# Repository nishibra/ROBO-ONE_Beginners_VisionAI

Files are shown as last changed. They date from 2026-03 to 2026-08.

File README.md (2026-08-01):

# ROBO-ONE_Beginners_VisionAI型ロボット

操縦型と自律制御型と同じ外形でカメラを搭載したロボットです。CPUにはRaspi5を使用し、深層機械学習や深層強化学習に加えてフィジカルAIなどを戦いを通して学べる教材として提供するものです。

---
### [機械設計](Mechanical_Design.md)
### [電子回路](Electronic_Circuit.md)
- 2026/8/1 "製作費を抑えた低コストバージョン"の説明を追加しました。
### [ソフトウェア](Software.md)
### [シミュレーション](Simulation.md)
---
### ROBO-ONE Beginners movies [動画](https://www.youtube.com/channel/UCuxCMnABbm_D5GusLxcCyIQ)
### ROBO-ONE Beginners 競技規則　[競技規則](https://github.com/nishibra/ROBO-ONE_Beginners)
---

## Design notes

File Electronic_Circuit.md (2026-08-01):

### ROBO-ONE_Beginners_VisionAI
# Electronic_Circuit

## 概要
Raspi5とカメラを使用し画像処理や深層強化学習などフィジカルAIの学習が電子回路に詳しくなくても可能なものとします。
- cpu: Raspi5 RAM 4Gbyte以上　SDカード 64Gbyte以上
- Raspi Camera csi接続
- Hat:5v電源 serial servo control/ i2c/ fan control/ RTC
- IMU BNO055など i2c接続
- ADC ADS1115など i2c接続

### 全体図
まずはカメラとIMUでどこまでいけるかトライして頂けることを期待します。TofセンサーとPSDセンサーは搭載していません。PSDセンサーは必要なら搭載できるようBKTは準備しました。ハットを使用しできるだけはんだ付けを少なくしました。

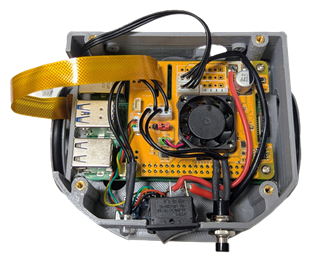
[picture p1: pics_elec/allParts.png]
RaspiAll


### Raspi5
ここではRaspi5を使用します。Raspi4でもほとんどのサンプルは動作しますが遅くです。スタートとして使用するには可能です。メモリーは4G以上あれば良いでしょう。

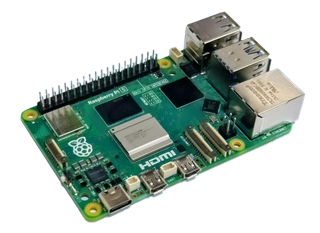
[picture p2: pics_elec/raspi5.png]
Raspi5


[Raspi5購入先](https://www.amazon.co.jp/dp/B0CPDJ8FNK?ref=ppx_yo2ov_dt_b_fed_asin_title)

### Hat
はんだ付けの極力避けるため以下のHatを使用します。Serial servo controlや電源、Fanが搭載されており、コンパクトで搭載性が非常に良いものです。

#### (BTE100B)(仕様変更中)
hat

[HAT購入先](https://www.besttechnology.co.jp/modules/knowledge/?BTE100B%20DXHAT)

#### HeatSink
画像処理を行うには電力消費が増大するためヒートシンクとFanの搭載が不可欠です。
以下のヒートシンクをRaspi5の赤丸部に貼り付けた後にハットを取り付けてください。

sink
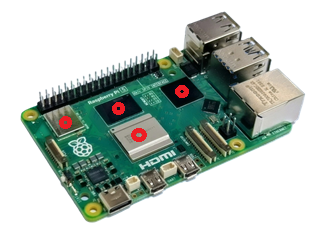
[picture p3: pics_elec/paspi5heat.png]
Pi5Heat


[Heatsink購入先](https://www.amazon.co.jp/dp/B0F8V6TK9M?ref=ppx_yo2ov_dt_b_fed_asin_title&th=1)

#### 電源廻り
電源スイッチはHatの電源入力とバッテリー接続コネクターの間に接続し写真のように取り付けます。ただしOSを週利用したのち電源スイッチを切るようにしてください。
右側のまどからRaspi5のスイッチが見えます。PCと接続していない場合はこのスイッチを長押ししてください。同じ窓から見えるLEDが赤くなってから電源を落として下さい。

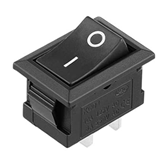
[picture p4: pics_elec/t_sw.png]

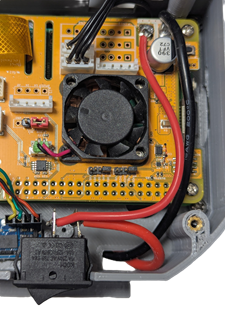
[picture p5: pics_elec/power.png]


このスイッチは以下より入手できます。

[sw購入先](https://www.amazon.co.jp/dp/B09QJQ55F8?ref=ppx_yo2ov_dt_b_fed_asin_title&th=1)

### CSI camera
Raspiカメラは以下を使用します。
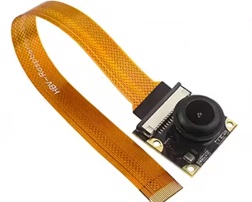
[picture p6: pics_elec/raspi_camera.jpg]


ハットを搭載する前にcam/disp 0にフラットケーブルを挿入しておきます。

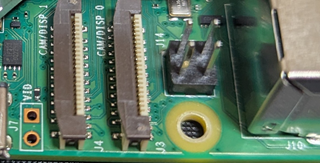
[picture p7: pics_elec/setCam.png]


#### camera: csi
Raspiカメラには以下のものがあります。レンズはFOV違いでいろいろありますが、130°程度が画像のひずみ変形も少なく使いやすいでしょう。

[Raspberry Pi 5 カメラ 5MP 1080P 130°](https://ja.aliexpress.com/item/1005006790000090.html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)

[1080Pミニカメラモジュール160°広角 購入先](https://www.amazon.co.jp/dp/B0D2BMH1BB?ref=ppx_yo2ov_dt_b_fed_asin_title)

#### Flexible cable
フラットケーブルは10～15cmの長さのものを使用します。

[CSIケーブル 15-22pin FPC フレキシブル 100mm購入先](https://www.amazon.co.jp/dp/B0DNFP5QJR?ref=ppx_yo2ov_dt_b_fed_asin_title&th=1)

### 入出力
#### IMU bno055
I2CにQWICコネクターで接続します。ROBO-ONE Beginners autoと同様に接続してください。

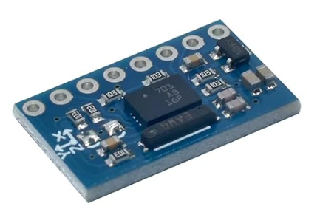
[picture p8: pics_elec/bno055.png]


[Qwic I2C コネクター購入先](https://www.amazon.co.jp/elechawk-%E3%82%B1%E3%83%BC%E3%83%96%E3%83%AB%E3%82%AD%E3%83%83%E3%83%88-SparkFun-%E3%82%BB%E3%83%B3%E3%82%B5%E3%83%BC%E3%83%9C%E3%83%BC%E3%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)

CPU caseには下の写真のように配置します。ロボットの前後がX軸、左右がY軸、基板面に垂直な方向がZ軸です。

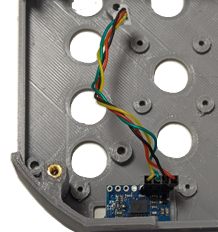
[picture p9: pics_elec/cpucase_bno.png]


#### push sw　および LED
push sw　および LEDはROBO-ONE Beginners autoと同じものが使用できます。以下のものも使えamazonでも入手できます。

sw

[push_sw購入先](https://www.amazon.co.jp/dp/B0D4PX1V4Q?ref=ppx_yo2ov_dt_b_fed_asin_title)

回路図は以下の通りで、スイッチのプルアップ抵抗はRaspi5の内部でブルアップすれば取り付ける必要はありません。

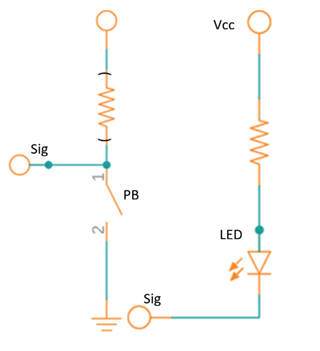
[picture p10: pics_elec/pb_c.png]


以下のようにはんだ付けし熱収縮チューブで被覆します。

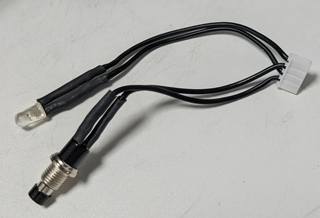
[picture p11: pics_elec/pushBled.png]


#### ADC
Raspi5ではI2Cを通してADCを接続し、PSDからのアナログ値を距離に変換して使用します。

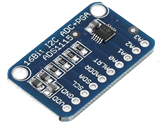
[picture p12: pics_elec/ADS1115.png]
ADC


[ADC購入先](https://www.amazon.co.jp/Walfront-1%E5%80%8BADS1115-16%E3%83%93%E3%83%83%E3%83%88I2C-ADC%E9%96%8B%E7%99%BA%E3%83%9C%E3%83%BC%E3%83%89%E3%82%A2%E3%83%8A%E3%83%AD%E3%8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)

### battery
Zeeeのバッテリーは比較的安定して使用できます。10個1年使用して今のところ問題ありません。
1350mAhのバッテリーを使用できます。2200mAhのバッテリーも搭載可能です。

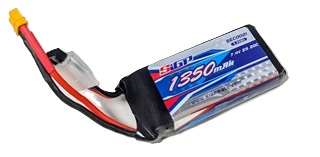
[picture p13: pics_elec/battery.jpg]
Battery


## servo:KRS3301/KRS3304-R2
KRS-3300シリーズのすべてのサーボモーターを使用できると同時にバッテリー(Lipoバッテリー2セル/7.4Vなど)は自由に自己責任で使用できます。
サーボモータについては通常KRS-3301を使用します。倒立伸子を行う場合はKRS3304-R2を使うと良いでしょう。
サーボの設定はROBO-ONE Beginners autoと同じとしますがトルク特性は以下のように少し変更した方がシミュレーションと会わせやすいでしょう。

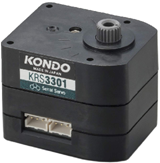
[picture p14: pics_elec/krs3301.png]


[サーボ購入先](https://kondo-robot.com/product/krs-3304r2-ics)

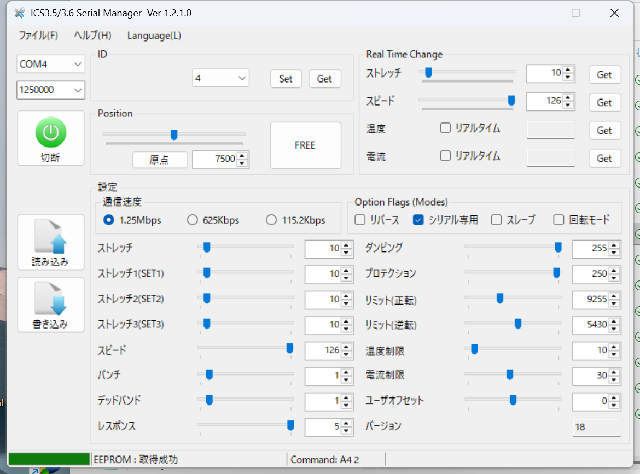
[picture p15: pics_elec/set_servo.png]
servo


---
#### BTE100Bのconfig.txtに追記する情報

プッシュスイッチを押下するとログアウト
```
[all]
dtoverlay=gpio-shutdown,gpio_pin=17
dtoverlay=gpio-poweroff,gpiopin=4,active_low=1
```
LinuxをGUIで起動している場合は、プッシュスイッチを押下するとログアウトのプロンプトが表示され、タイムアウトするかダイアログのpower offを選択するまでシャットダウンが行われません。プッシュスイッチ操作によってシンプルにシャットダウン処理を行わせるには、GNOMEの設定を変更する必要があります。なおログインしていない状態ではこの設定は効果がありません。

```
gsettings set org.gnome.SessionManager logout-prompt false
```
冷却ファンのON-OFF
```
[all]
dtoverlay=gpio-fan,gpiopin=19,temp=50000
temp=50000は50℃で冷却ファンをONする意味で、摂氏度の1000倍の値を指定
設定温度を10℃下回るとファンはOFFする
```
RTC
```
[pi5]
dtparam=rtc=off
[all]
dtparam=i2c_arm=on
dtoverlay=i2c-rtc,ds3231
```
UART
```
[pi3]
init_uart_clock=64000000
dtoverlay=uart0=on
dtoverlay=pi3-miniuart-bt
 
[pi4]
init_uart_clock=64000000
#UART1を活性化
dtoverlay=uart1,txd1_pin=14,rxd1_pin=15
#UART2を活性化
dtoverlay=uart2,txd2_pin=0,rxd2_pin=1
#UART4を活性化
dtoverlay=uart4,txd4_pin=8,rxd4_pin=9
使用するポートのみを活性化する事を推奨。Linux上でのデバイス名は概ねttyAMAのプレフィクスで始まる。
またRaspberry Pi 3/Zeroの場合はcmdline.txtに記述されている「console=serial0,115200」を削除する事
```

---
## 製作費を抑えた低コストバージョン
最近は半導体の価格が上がっているため、できるだけコストを抑えて製作できる方法を検討しました。
また、これまでのモデル（auto）からの移行もスムーズに行えるよう、共通で使える部品を可能な限り採用しています。

### メモリ（RAM）の見直しによるコスト削減
Raspberry Pi 5 は搭載されているメモリ容量によって価格が大きく変わります。
今回のように **RAM 2GB や 1GB のモデルを選ぶことで、本体費用をぐっと安く抑えることが可能**です。
もし運用中にメモリが足りなくなった場合でも、**画像処理の解像度を少し落とすなどの工夫で十分対応できる**見込みです。

### 部品の購入先リンク
製作に必要な部品の購入先一覧です。

* **Raspberry Pi 5 (2GB RAM)**
[購入先](https://www.amazon.co.jp/Raspberry-Pi-SC1110-5-2GB-RAM%E3%80%82/dp/B0DDL91V2R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)
* **Raspberry Pi 5 (1GB RAM)**
[購入先](https://www.amazon.co.jp/Raspberry-Pi-1GB-RAM-%E3%80%82/dp/B0G668D1R8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)
* **高効率 8A DC-DC 降圧コンバータボード（25V → 3.3V/5V/9V/12V）**
[購入先](https://ja.aliexpress.com/item/1005009516551580.html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)

### 構成と写真のご案内
写真と合わせて配線や接続のイメージをご確認ください。

* **構成全体写真**
ファン付きの Raspberry Pi 5 に、5V電源・IMU（慣性計測装置）・シリアル変換ボード・サーボ分配器を取り付けた状態です。IMU（慣性計測装置）・シリアル変換ボード・サーボ分配器はautoのものを使用します。

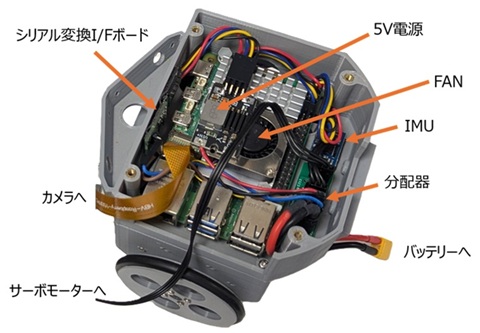
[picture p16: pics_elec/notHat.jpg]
全体図


* **実態配線図**
Raspberry Pi 5 に5V電源、シリアル変換ボード、サーボ分配器を接続した配線図です。

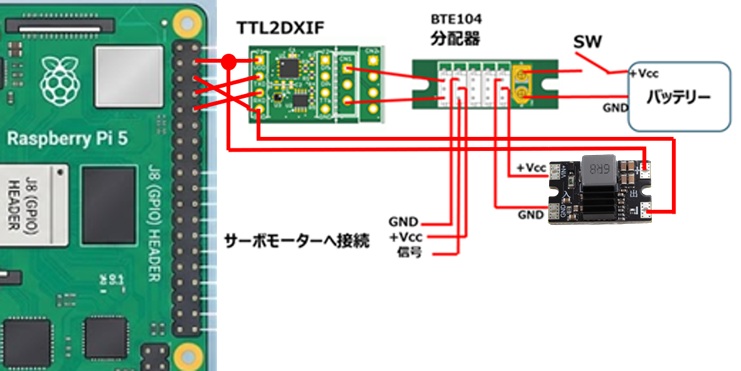
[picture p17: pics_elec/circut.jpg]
配線図


* **IMU接続写真**
Raspberry Pi 5 に IMU を I2C 接続した様子です。

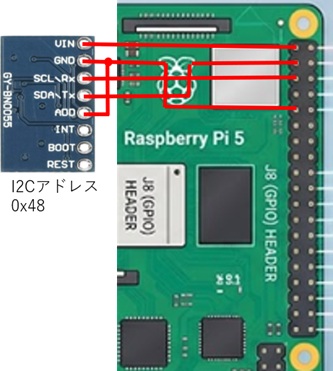
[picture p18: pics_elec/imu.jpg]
IMU接続図


### 組み立てのコツと注意点

* **組み立てやすさ**
はんだ付けを行う箇所は数か所だけですので、電子工作が初めての方や初心者の方でも比較的簡単に作ることができます。
* **パーツの固定方法**

   **サーボ分配器：** 固定用のボスが付いているため、ビス（ネジ）でしっかり固定できます。

   **その他のボード：** ショートを防ぐため、絶縁に気を付けながら両面テープ等で固定してください。

* **プログラムの互換性**
I2Cアドレスおよびシリアルポートの設定は HAT（拡張基板）を使用した時と同じになっています。そのため、**既存のプログラムをそのまま変更せずに動かすことが可能**です。

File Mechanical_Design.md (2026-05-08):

### ROBO-ONE_Beginners_VisionAI
# Mechanical_Design

## 1.コンセプト
このロボットはRaspberry Pi 5を使った画像処理やAIの学習向けのロボットです。
外形寸法はROBO-ONE Beginners auto型と同じですがCPUはRaspi picoからRaspi-5に替わり、カメラが搭載されます。足回りとアーム部は部品点数の低減と組み立て性の改善を図りました。Raspi5を使用し深層学習を実行することから電力消費増と発熱への対応とバッテリの容量アップ品の搭載が可能なものとしました。
#### 全体写真
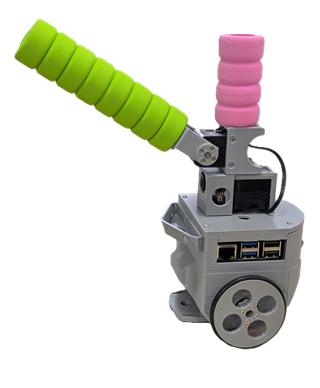
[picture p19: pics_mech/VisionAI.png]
VisionAI

#### 全体図
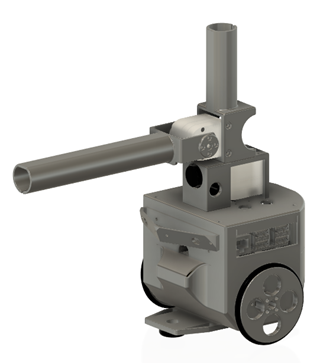
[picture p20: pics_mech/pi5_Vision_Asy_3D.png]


## 2.CPU case
外形寸法はROBO-ONE Beginners autoのpico CPU caseと同じサイズに収めました。後部のPSD用ブラケットはCPU caseと一体化、前方は分離型のままでTofセンサーは廃止しカメラを使った画像処理で対応することとします。
#### CPU case
CPU case cover締め付けボスにM2.5のインサートを挿入しておきます。挿入方法はROBO-ONE Beginners autoと同じですのでそちらをご参照ください。
CPUはM2.5-8mmのねじでケース下より締め付けます。

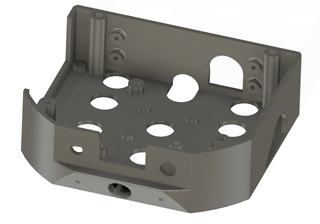
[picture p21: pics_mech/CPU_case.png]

VisionAI

下の写真のように事前にヒートシンクを取り付けたCPUボードとハットをマウント用ディスタンスにねじM2.5-4mmをハット上部にねじで締め付けておきます。この時カメラ用フラットケーブルを接続しておきます。詳細は電子回路編でご確認ください。

VisionAI

### PSD BKT
PSD BKTはCPU caseにM2-5mmのタッピングビスでねじ止めします。

VisionAI

### CPU case cover
CPU case coverはCPU caseに4本のM2.5-8mmねじで締め付けます。更にアームまわりを搭載します。

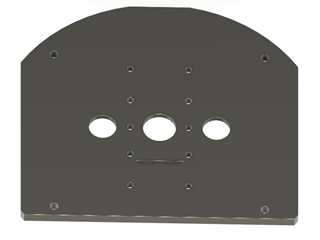
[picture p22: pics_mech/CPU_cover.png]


## 3.アーム廻り
アーム廻りは写真のように組み立てます。

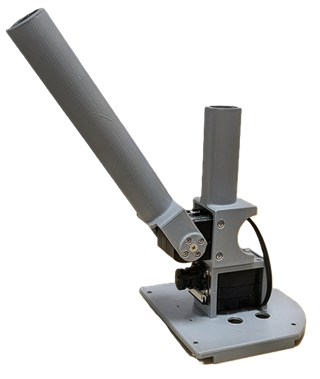
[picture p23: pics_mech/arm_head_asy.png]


#### Pan servo bkt
Pan servo bktにはPan用サーボモーターを4本のM2-5mmで締め付けます。CPU case coverとPan servo bktは4本のM2-10mmタッピングビスで締め付けます。

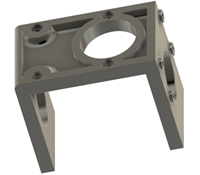
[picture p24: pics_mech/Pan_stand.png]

VisionAI

Pan_standを3dプリンターで製作する場合はBrimをつけ、横方向からプリントするようにします。

#### Tilt_bkt and Head
Tiltサーボモーターの固定とヘッドを一体化しました。サーボホーンとの締め付けはM2-8mmのねじで、サーボとの締め付けはM3-8mm(近藤科学M3-8低頭ホーン止めビス)で締め付けます。渋りが無いことを確認します。渋りがある場合はペーパーやすりなどで渋り面を仕上げます。

VisionAI

#### Arm
アームとBKTを一体化しました。サーボホーンは両軸とし、いずれもM2-5mmのねじで締め付けます。

VisionAI

### Head と Armの保護

Head部とArm部には安全や器物保護のためスポンジのドアノブカバーを使用します。
ピンクと紫は半分に切ってHead部に使用します。赤コーナーの場合はピンク、青コーナーは紫です。Headおよびアームはそれぞれスポンジを交換しやすくするためにスリットを入れています。

donb  

[購入先](https://amzn.asia/d/89CXsD9) 

購入にあたっては似たようないくつかの製品があり、内径寸法が多少異なる場合がありますので注意してください。

### カメラの取り付け
カメラの取り付けは4本のM2-5mmのタッピングビスで締め付けます。CPUカバーのスリット部からカメラ用フラットケーブルを引き出し接続します。裏表がありますので間違えないようにしてください。

VisionAI

#### camera cover
Camera coverはパチッというまで押し込むと固定されます。

VisionAI

### 4.足回り

ロボットのセンサー、電子回路、ソフトウェアは自由に変更できるものとします。またKRS-3300シリーズのすべてのサーボモーターを使用できると同時にバッテリー(Lipoバッテリー2セル/7.4Vなど)は自由に自己責任で使用できます。

### Wheel
wheelは1partsとしました。O-ringを入れることで完成です。

VisionAI
VisionAI

O-ringは以下より購入可能です。

[5個入り Oリング ニトリルゴム 50mm x 60mm x 5mm ブラック](https://www.amazon.co.jp/dp/B07W3BR9TY?ref=ppx_yo2ov_dt_b_fed_asin_title&th=1)

サーボモータにはサーボホーンに直接取り付けることができます。ねじはM2-12mmを使用してください。

VisionAI 
  
### シャーシ
キャスタ部にはスライダーを採用しました。滑りやすくなり走行抵抗や走行音が少なくなりました。スライダーはシャーシの取り付け部丸い部分のセンターに取り付けてます。このピッチが90mm,70mm,50mmとあり、昇段昇級の審査に使われます。ボディとの取り付けはM2-10mmのタッピングビスで取り付けます。

VisionAI
VisionAI

[スライダー購入先](https://www.amazon.co.jp/dp/B0DFGZZ4GH?ref=ppx_yo2ov_dt_b_fed_asin_title)

### body
モノコックとし、サーボモータを90度毎に自由にセットできるようにしました。これにより容量の大きなバッテリーの搭載が可能となります。
リチウムポリマーの7.4V2000mAH程度のバッテリーの搭載が工夫次第で可能です。
CPUケースの取り付けボス部にはインサートを埋め込みます。
M2.5のインサートを使用しています。

VisionAI
VisionAI

上の写真のようにサーボモーターを配置するとしたの写真のようにバッテリーが搭載でき、重量バランスがとりやくなります。またCPU caseをくみ上げる前にサーボモーターの設定は行っておきます。ボーレイト125000、IDは右側を1、左側を2と設定するとサンプルプログラムがそのまま使えます。

VisionAI

### Battery cover
バッテリの交換性向上のため、Battery coverのねじ止めはやめ、パッチンと挿入できるようにしました。バッテリーを交換したらカバーの片側を挿入し反対側を押し込んでください。外すときは上部の半円の部分に爪で出ているのでこれを引っ張り外してください。3Dプリンターで製作する場合はBrimを付けてください。

VisionAI
VisionAI

### stlデータ
3dprinterで使用できるstlファイルはstlフォルダーにありますのでご利用ください。セット面をサポートなしでプリントできるよう考えて見てください。すべてサポートなしでプリント可能です。

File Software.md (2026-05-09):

### ROBO-ONE_Beginners_VisionAI
# Software
## コンセプト
このロボットはRaspberry Pi 5を使用した初心者向けのVision AI型ロボットです。最新のAIライブラリを活用し、物体認識などの機械学習や、シミュレーションを用いた強化学習を学ぶことができます。

## ハード / OS / I/O 概要

* **CPU**: Raspberry Pi 5 (Memory 4GB以上推奨)
* **OS**: Raspberry Pi OS Trixie (Debian 13) 64-bit
* **言語**: Python 3.11以降
* **通信プロトコル**:
　* **Serial (UART)**: サーボモーター制御用 (KRSサーボ等)
　* **I2C**: IMU (慣性計測装置) / ADC (アナログ-デジタル変換) 用

## Install 手順
### 1. SDカードの作成
Raspberry Pi Imagerを使用し、Device:Raspi5 OS:Trixieを選択します。

gameController

* **OS**: Raspberry Pi OS (64-bit) Trixie
* **設定**: 書き込み時に「OSカスタマイズ」でホスト名、Wi-Fi、SSHを有効にしておくと、その後の作業がスムーズです。

### 2. OSとConfigの設定

Raspberry Pi 5を起動し、ターミナルで以下の設定を行います。

#### インターフェースの有効化

`sudo raspi-config` を実行し、以下の項目を **Enable** にします。

* Interface Options -> **I2C**
* Interface Options -> **Serial Port** (Login shell: No / Hardware: Yes)
* Interface Options -> **VNC** (必要に応じて)

#### Raspberry Pi Connect のセットアップ

ブラウザ経由でリモートデスクトップ操作を可能にします。

```bash
sudo apt update
sudo apt install rpi-connect
# インストール後、画面右上のアイコンまたはコマンドでサインイン

```

#### 冷却ファンの設定

`sudo nano /boot/firmware/config.txt` を開き、末尾に追記します。

```text
[all]
dtoverlay=gpio-fan,gpiopin=19,temp=50000

```

> **Note**: `temp=50000` は50℃でファンが始動することを意味します。AI処理中は発熱が激しいため、この設定は必須です。

### 3. I/O関係の接続確認

接続されたデバイスが認識されているか確認します。

```bash
# I2Cデバイスの確認（アドレスが表示されればOK）
i2cdetect -y 1

# シリアルポートの確認
ls /dev/ttyAMA0

```

## 開発環境（venv）の構築

OS標準のPython環境を汚さないよう、仮想環境（venv）を使用します。Trixieでは `pip install` を直接行うとエラーになるため、この手順は必須です。

### 仮想環境の作成と有効化

```bash
sudo apt update && sudo apt upgrade -y
mkdir ~/robot_project
cd ~/robot_project

# システムパッケージ（Picamera2など）を共有して作成
python3 -m venv venv --system-site-packages

# 有効化（作業開始時に毎回実行）
source venv/bin/activate
```
### 必要なライブラリのインストール
シミュレーション環境や画像処理のライブラリーをインストールします。mujocoやYoloがRaspi5でも使えます。

```bash
pip install --upgrade pip
pip install ultralytics  # YOLO (物体認識)
pip install mujoco gymnasium stable-baselines3  # 強化学習セット
pip install numpy

```
* Yolo26: `ultralytics` を入れることで、OpenCVも導入されるので、カメラ映像から即座にリアルタイム物体検知や処理が可能になります。
* 起動時自動実行: ロボットとして自律動作させる場合は、`systemd` を使って venv 内の python スクリプトを自動起動する設定を追加すると便利です。
* 電力不足注意: Raspberry Pi 5は 5V/5A の電源を推奨します。AI処理中にカメラやサーボを動かすと電圧降下（低電圧警告）が発生しやすいため、高品質な電源を使用してください。

---
## カメラ（rpicam-apps / Picamera2）の使い方
Raspberry Pi 5では従来の `raspistill` ではなく `rpicam-apps` を使用します。

### 基本コマンド
* プレビュー表示: `rpicam-hello -t 0`
* カメラ一覧確認: `rpicam-hello --list-cameras`
* 静止画保存: `rpicam-still -o test.jpg`

### Pythonでの画像処理
OpenCVとPicamera2を組み合わせる際、色の並び（色空間）に注意が必要です。
* 色の変換: Picamera2は RGB形式で画像を取得しますが、OpenCV（cv2）はBGR形式として処理します。
```python
# 変換例
import cv2
img_bgr = cv2.cvtColor(img_rgb, cv2.COLOR_RGB2BGR)
```
* フォーマット: メモリ効率を上げるため、`format='RGB888'` を指定してキャプチャすることを推奨します。

pi-cameraのsample programを以下に置きました。

example/etc/picamcam.py

---
## YOLO11の使用方法

YOLOはどんどん進化しており、簡単にインストールでき、使用できる便利な物体認識の深層学習手法です。また最近エッジおよび低電力デバイス向けに設計されたYOLO26も使えます。

[Yolo26](https://docs.ultralytics.com/ja/models/yolo26/)

以下はYolo11の物体認識のプログラムです。

example/etc/inf11_cam.py

---

## KRSのコントロール
krs-driver_rp5.pyはROBO-ONE Beginners autoのシリアルポートを変更したものです。使い方は同じです。

## IMU I2C取り込み
BNO055をi2cのボートと使用するライブラリーを変更すれば、使用方法はROBO-ONE Beginners autのものと同じです。

## ADC PSD取り込み
Raspi5にはADCが無いので、i2c接続のADCを使用します。
Raspberry Pi 5（ラズパイ5）で高性能な16bit ADC（アナログ-デジタルコンバータ）である**ADS1115**を使用する方法を解説します。
ラズパイ5では、これまでのモデルと異なりGPIOの制御方式が変更されていますが、Pythonのライブラリ（Adafruit CircuitPython）を使用すれば、従来通り簡単に扱うことができます。

### 1. 配線（接続方法）

ADS1115は**I2C**プロトコルを使用します。ラズパイ5のピン配置に合わせて以下のように接続してください。

| ADS1115 ピン | Raspberry Pi 5 ピン | 役割 |
| :--- | :--- | :--- |
| **VDD** | 3.3V (Pin 1) | 電源 (3.3V推奨) |
| **GND** | GND (Pin 9) | グラウンド |
| **SCL** | SCL (Pin 5) | I2C クロック |
| **SDA** | SDA (Pin 3) | I2C データ |
| **ADDR** | GNDへ接続 | I2Cアドレスを `0x48` に設定 |

### 2. ラズパイの設定

まず、I2Cインターフェースを有効にする必要があります。

1.  ターミナルで `sudo raspi-config` を実行。
2.  **Interface Options** -> **I2C** を選択し、**Yes** を選んで有効化します。
3.  再起動後、正しく認識されているか確認します。
    ```bash
    ls /dev/i2c*
    ```
    `/dev/i2c-1` が表示されればOKです。

### 3. ライブラリのインストール

ラズパイ5では、Python環境の競合を避けるために**仮想環境（venv）**の使用が推奨されています。

```bash
# 仮想環境の作成と有効化
python -m venv env
source env/bin/activate

# 必要なライブラリのインストール
pip install adafruit-circuitpython-ads1x15
```
### 4. Pythonコードの例
以下のコードは、`A0`ピンに入力された電圧を読み取り、コンソールに表示するシンプルな例です。

```python
import time
import board
import busio
import adafruit_ads1x15.ads1115 as ADS
from adafruit_ads1x15.analog_in import AnalogIn

# I2Cバスの初期化
i2c = busio.I2C(board.SCL, board.SDA)

# ADS1115オブジェクトの作成
ads = ADS.ADS1115(i2c)

# A0ピンをアナログ入力として設定
chan = AnalogIn(ads, ADS.P0)

print(f"{'電圧(V)':>10} {'数値':>10}")
print("-" * 25)

try:
    while True:
        # chan.value は 0-65535 の範囲 (16bit)
        # chan.voltage は 実際の電圧
        print(f"{chan.voltage:10.4f}V {chan.value:10}")
        time.sleep(0.5)
except KeyboardInterrupt:
    print("\n終了します")
```

知っておくと役立つポイント
* ゲイン（増幅率）の設定:
    デフォルトでは最大4.096Vまで測定可能です。これより小さい電圧を精密に測りたい場合は、`ads.gain = 2`（最大2.048V）のように設定変更できます。
* 差動入力:
    2つのピンの電圧差を測る場合は、`AnalogIn(ads, ADS.P0, ADS.P1)` のように指定します。
* サンプリングレート:
    `ads.data_rate = 860` と設定することで、秒間最大860回の高速サンプリングが可能です。
---

## Game controllerの接続
RaspiOSに接続します。Raspi ConnectからRaspiに接続します。Bluetoothを探して接続します。いろいろなコントローラーが接続できると思います。
ここでは8bitDo lite2に接続します。

gameController
gameController

[購入先](https://www.amazon.co.jp/8BitDo-Lite-Switch%E3%80%81Switch-Lite%E3%80%81Android%E3%80%81Raspberry-Pi%EF%BC%88%E3%82%BF%E3%83%BC%E3%82%B3%E3%82%A4%E3%82%BA%EF%BC%89%E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)

#### Game controllerのサンプルプログラム
以下のプログラムは4軸のサーボモータをコントロールするprogramです。ここまでで出来れば操縦型で参加できます。

example/etc/joy.py
```python
import pygame
import time
import serial
from krs_driver_rp5 import * 
#servo id
id_r=1
id_l=2
id_pan=3
id_tilt=4
#
ct=7500
ct_pan=6128
ct_tilt=7500
#
krs=KRSdriver()
#
def arm(pan,tilt):
    krs.set_position_ret(id_pan,ct_pan+pan)
    krs.set_position_ret(id_tilt,ct_tilt-tilt)
#
def drive(r_sp,l_sp):
    krs.set_position_ret(2,ct-l_sp)
    krs.set_position_ret(1,ct+r_sp)
#
def free_all():
    krs.read_position_set_free(1)
    krs.read_position_set_free(2)
    krs.read_position_set_free(3)
    krs.read_position_set_free(4)  
#
def main():
	# Pygameの初期化（コントローラー用）
    pygame.init()
    pygame.joystick.init()
    while pygame.joystick.get_count() == 0:
        pygame.event.pump() # イベントキューを更新
        time.sleep(0.1)     # CPU負荷を抑えるための待機
    joystick = pygame.joystick.Joystick(0)
    joystick.init()
    print(f"Using: {joystick.get_name()}")
    #
    try:
        while(True) :
            pygame.event.pump()
            bu=joystick.get_button(0) # A
            bu2=joystick.get_button(1)# B
            bu3=joystick.get_button(3)# Y
            bu4=joystick.get_button(4)# Y
            bu6=joystick.get_button(6)# L1
            bu8=joystick.get_button(8)# L1
            if bu!=0: 
                drive(0,0)
            elif bu2!=0:
                free_all()
            elif bu6!=0:
                arm(int(5000*joystick.get_axis(2)),2800)
            elif bu8!=0:
                arm(int(5000*joystick.get_axis(2)),-3800)                
            else:
                fr=int(-300*joystick.get_axis(1))
                rf=int(100*joystick.get_axis(0))
                arm(int(5000*joystick.get_axis(2)),int(-5000*joystick.get_axis(3)))
                drive(fr-rf,fr+rf)
            time.sleep(0.01)
    except KeyboardInterrupt:
        print("\n終了します")
        pygame.quit()
        free_all()
#
if __name__ == "__main__":
    main()
```

---

## systemd による自動起動の設定手順
大会では電源を入れれば自動起動で操縦可能にします。

### 1. サービスファイルの作成

以下のコマンドで、新しいサービス設定ファイルを作成します（ファイル名は `my_robot.service` とします）。

```bash
sudo nano /etc/systemd/system/my_robot.service

```

### 2. 設定内容の記述

以下の内容をコピー＆ペーストしてください。各パスはご自身の環境に合わせて書き換えてください。

```ini
[Unit]
Description=My Vision AI Robot Service
After=network.target

[Service]
# 実行ユーザー（通常は pi）
User=nishi
# プログラムがあるディレクトリ
WorkingDirectory=/home/nishi/begin
# 仮想環境内のpythonパスを直接指定して実行
ExecStart=/home/nishi/begin/venv/bin/python3 /home/nishi/begin/rf/main.py
# 異常終了した時に5秒後に再起動する設定
Restart=always
RestartSec=5
# 標準出力（ログ）の送り先
StandardOutput=inherit
StandardError=inherit

[Install]
WantedBy=multi-user.target

```

### 3. サービスの有効化と起動

ファイルを保存（`Ctrl+O` -> `Enter`）し、エディタを終了（`Ctrl+X`）したら、以下のコマンドでシステムに反映させます。

```bash
# 設定の再読み込み
sudo systemctl daemon-reload

# 自動起動の有効化
sudo systemctl enable my_robot.service
# 無効化
sudo systemctl disable my_robot.service
# 今すぐ起動（テスト）
sudo systemctl start my_robot.service

```
### 4. 運用で役立つコマンド

自動起動を設定した後は、画面に何も表示されないため「本当に動いているか？」を確認する術を知っておく必要があります。

* **状態の確認**:
`systemctl status my_robot.service`
（実行中か、エラーで止まっているかが一目でわかります）
* **ログのリアルタイム確認**:
`journalctl -u my_robot.service -f`
（Pythonの `print()` 内容をリアルタイムで監視できます。デバッグに最適です）
* **停止・再起動**:
`sudo systemctl stop my_robot.service` / `sudo systemctl restart my_robot.service`---

---

## 【補足】Raspberry Pi Connect の導入・利用手順

Raspberry Pi Connectを使うと、ブラウザ越しにどこからでもRaspberry Piのデスクトップにアクセスできます。セットアップを以下のステップに分けて解説します。

### 1. 準備：OSのインストール

Raspberry Pi Connectを利用するには、OSのバージョンと種類が重要です。

* **OSの選択:** **Raspberry Pi OS (64-bit)** の最新版（Bookworm以降）をインストールしてください。
* ※Raspberry Pi 4 / 5 / 400 が推奨されています。
* ※デスクトップ版（Desktop）を選択してください（Lite版は非対応です）。

* **書き込み:** 公式の「Raspberry Pi Imager」を使ってmicroSDカード（またはSSD）に書き込み、Raspberry Piを起動します。

### 2. Raspberry Pi ID の作成

あらかじめ、管理用の公式アカウントを作成しておくとスムーズです。

* [Raspberry Pi ID 登録ページ](https://id.raspberrypi.com/) にアクセスし、メールアドレスでアカウントを作成・サインインしておきます。

### 3. Connect サービスの有効化（本体側の操作）

Raspberry Piが起動したら、機能をオンにします。

1. **インストール（必要な場合）:**
ターミナルを開き、念のため最新の状態に更新してインストールを確認します。
```bash
sudo apt update
sudo apt install rpi-connect

```

2. **機能を有効化:**
メニューの「設定」→「Raspberry Pi Configuration」→「Interfaces」タブの中に「Raspberry Pi Connect」という項目があれば **ON** にします。
（または、ターミナルで `systemctl --user enable rpi-connect` を実行します）

### 4. デバイスの紐付け（リンク）

ここが最も重要なステップです。

1. Raspberry Piのデスクトップ右上（タスクバー）に、Connectのアイコン（雲のようなマーク）が表示されます。
2. アイコンをクリックし、**[Sign In]** を選択します。
3. ブラウザが立ち上がり、「このRaspberry Piをあなたのアカウントに登録しますか？」という画面（Link Device）が表示されます。
4. **デバイス名を入力:** 自分が管理しやすい名前（例: `My-RasPi5` など）を付けて、[Link Device] ボタンを押します。

### 5. 外部から接続する

設定が完了したら、別のPCやスマホのブラウザから操作可能です。

1. 接続元PCのブラウザで [https://connect.raspberrypi.com/devices](https://connect.raspberrypi.com/devices) にアクセスします。
2. 自分のRaspberry Pi IDでサインインします。
3. 登録したデバイスの一覧が表示されるので、右側にある **[Connect]** ボタンをクリックします。
4. これでブラウザ内にRaspberry Piのデスクトップが表示されます！

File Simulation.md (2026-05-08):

### ROBO-ONE_Beginners_VisionAI
# Simulation
Mujocoを使った物理シミュレーションにより、深層強化学習や模倣学習の実習ができるようにします。

### 環境
- Windows11
- Python 
- Mujoco シミュレーション

---
### Pythonのインストール手順 (Windows)
* 公式サイトからダウンロード: Python.orgにアクセスし、Windows用の最新版インストーラー（64-bit）をダウンロードします。
* インストール実行: ダウンロードしたファイルを実行します。
* Pathへの追加 (最重要): 最初の画面下部にある「Add Python.exe to PATH」のチェックボックスを必ずチェックします。
* インストール: 「Install Now」をクリックします。
* インストール完了: 完了画面が出たら「Close」を押します。 

### インストールの確認
Windowsターミナル（またはコマンドプロンプト/PowerShell）を開き、以下のコマンドを入力してバージョンが表示されれば成功です。 

```bash
python --version
```
## 開発環境（venv）の構築
OS標準のPython環境を汚さないよう、仮想環境（venv）を使用します。

python3 -m venv venv 

### 有効化（作業開始時に毎回実行）
```
.\venv\Scripts\activate

必要なライブラリのインストール
python.exe -m pip install --upgrade pip
pip install ultralytics  # YOLO (物体認識)
pip install mujoco gymnasium stable-baselines3  # 強化学習セット
pip install numpy
```

[venvについて](https://saas.n-works.link/programming/python/python_virtualenv_how_to_buildavirtualenvironment)

---

## Mujocoについて

Mujocoについては以下のサイトなどをご参照ください。

[物理エンジンMuJoCoの紹介](https://qiita.com/Yayoi-Habami/items/1bf5a3e05b1516a90381)

URDFとMujoco modelの違い
* 1. 形状指定（size）の違い: URDFの <box size="0.1 0.1 0.5"/> は「全幅」ですが、MuJoCoの <geom size="0.05 0.05 0.25"/> は 中心からの距離（Half-extents） です。そのため、値を半分にする必要があります。

* 2. ジョイントの記述: URDF: parent と child を指定して繋ぐ。
MuJoCo: body タグを 入れ子（階層構造） にすることで親子関係を表現します。

* 3. アクチュエータ（Actuator）:
URDFには「どう動かすか」の記述がありませんが、MuJoCoでシミュレーションを行うには <actuator> セクションが必要です。ここでは、URDFの effort（30）を ctrlrange として設定したモータを定義しました。

* 4. 慣性の自動計算:
MuJoCoは非常に賢いので、<geom> に mass="1" と書くだけで、その形状（box）に基づいた適切な慣性テンソルを自動的に計算してくれます。URDFのように複雑な慣性行列を自分で書く必要はありません（もちろんカスタム設定も可能です）。

### (参考) VS Code のダウンロードとインストール
Windows の場合
* 公式サイトにアクセスし、**「Download for Windows」**をクリックしてインストーラー（.exe）をダウンロードします。

https://code.visualstudio.com/download
 
* ダウンロードしたファイルを実行し、基本的には「次へ」で進めます。
* ポイント: 途中の「追加タスクの選択」画面で、以下の 2 つにチェックを入れるのがおすすめです。
* 「エクスプローラーのファイルコンテキストメニューに [Code で開く] アクションを追加する」
* これを有効にすると、XML ファイルを右クリックしてすぐ VS Code で開けるようになります。

### 2. 重要な 4 つの要素
#### ① <body>（剛体）
ロボットの各パーツ（リンク）です。
* pos: 親の座標系から見た相対位置。
* quat または euler: 回転（クォータニオンまたはオイラー角）。
#### ② <joint>（関節）
その <body> が親に対してどう動くかを定義します。
*type: hinge（回転）, slide（直動）, free（浮遊）など。
* axis: 回転軸（例: 0 0 1 は z 軸まわり）。
* range: 可動範囲（例: -1.57 1.57）。

#### ③ <geom>（形状・物理特性）
見た目、当たり判定、そして質量を定義します。
* type: __box, sphere, cylinder, capsule, mesh（STLファイルなど）__
* size: 形状のサイズ。※注意：URDFと違い、中心からの距離（半径や半分の長さ）で指定します。
* mass: 質量。指定すると慣性モーメントを自動計算してくれます。

#### ④ <actuator>（動力）
ロボットをどう動かすか。worldbody の外に書きます。
* __motor: トルク制御。__
* __position: 位置制御（サーボモータに近い挙動）。__
* __velocity: 速度制御。__

#### <freejoint/>:
 車両全体がワールド内を移動できるようにするために必須です。これがないと、ロボットはその場に固定されてしまいます。

#### quat（クォータニオン）: 
 MuJoCoの円柱（cylinder）はデフォルトでZ軸方向を向いています。タイヤを横に向けるために quat="0.707 0.707 0 0" を使い、X軸まわりに90度回転させています。

#### キャスターの摩擦 (friction="0 0 0"): 
本来ならキャスターも可動パーツにするのが正確ですが、簡易モデルでは球体（sphere）を配置し、摩擦をゼロに設定することで、床の上を滑る「支え」として機能させます。

#### <velocity> アクチュエータ: 
車輪の制御には motor（トルク制御）よりも velocity（速度制御）を使うのが直感的です。data.ctrl[0] に値を入れると、その速度（rad/s）でタイヤが回ります。

### 回転させたい方向
よく使う回転パターン表「とりあえずこれを試す」という値をまとめました。
```
  オイラー角 (euler)  クォータニオン (quat)
X軸まわりに90°  1.57 0 0    0.707 0.707 0 0
X軸まわりに180° 3.14 0 0    0 1 0 0
Y軸まわりに90°  0 1.57 0    0.707 0 0.707 0
Z軸まわりに90°  0 0 1.57    0.707 0 0 0.707
```
### プレビューしながら書く方法
VS CodeでXMLを書いている横で、MuJoCoの simulate アプリを開いておいてください。

__XMLを保存（Ctrl + S）。
simulate アプリの画面上で Ctrl + L（リロード）を押す。__

即座に変更が反映されます。

## Mujoco Modelの作成

| 番号 | 部品名 | 重量 | 個数 | 合計 |
| :--- | :--- | :--- | :--- | :--- |
| 1	| CPU case/cover/ CPU	| 170	| 1	| 170 |
| 2 | Wheel asy	| 15 | 2 | 30 | 
| 3 |	Arm asy	| 50 | 1 | 50 | 
| 4 | head asy	| 26 | 1 | 26 | 
| 5 | stand asy | 12 | 1 | 	12| 
| 6 | Body/chassis/Bat.cover	| 80	| 1| 	80 | 
| 7 | krs3301 | 28 | 4 | 112 | 
| 8 | Battery	| 90	| 1 | 	90 | 
|	| 合計		| | |	570 | 

Assyの重心はArmを中段の構えとし、X軸は両車輪の中心、y軸は両車輪の回転中心軸を結ぶ洗浄に、Z軸はCPU case 下面より5mm位置にあるものとします。
バッテリー位置や構えによって重心位置は異なります。異なる点はモデルに反映してください。
### Beginners Mujoco model
BeginnersのMujoco modelを作成しました。

example/balance/2wheel_balance_KRS3304R2.xml

### PID制御で倒立伸子
以下はMujoco modelをPID制御で倒立伸子を制御するScriptです。

example/balance/pid_balance_control.py

### 深層強化学習で倒立伸子
以下はMujoco modelを 深層強化学習で倒立伸子を制御するScriptです。

#### 学習

example/balance/reinf_learning_balance.py
example/balance/t2_kxrR2_balance_model.zip

#### 予測

example/balance/reinf_predict_balance.py

#### 参考 深層強化学習サンプル

example/getup

### 強化学習の学習プロセスの確認
強化学習の学習プロセス（`ppo_1` フォルダに保存されているログ）を確認するには、**TensorBoard** を使用するのが最も一般的で確実な方法です。
Stable Baselines3（SB3）は、学習中の報酬（reward）やエピソードの長さ、損失関数（loss）などのデータを TensorBoard 形式で書き出します。
以下の手順で表示してください。

#### 1. TensorBoardの起動
ターミナル（またはコマンドプロンプト）を開き、Pythonスクリプトを実行しているディレクトリで以下のコマンドを入力します。
```bash
tensorboard kxr_balance_tb/PPO_1
```
※ `PPO_1` の親ディレクトリにいる場合は、上記コマンドでその中の全てのログを読み込みます。

ライブラリがインストールされているか確認
TensorBoard自体がPython環境に入っているか確認し、入っていなければインストールします。
```bash
pip install tensorboard
```
#### 2. ブラウザでの確認
コマンドを実行すると、以下のようなメッセージが表示されます。
`TensorBoard 2.x.x at http://localhost:6006/ (Press CTRL+C to quit)`

ブラウザ（ChromeやEdgeなど）を開き、アドレスバーに以下を入力してください。
**`http://localhost:6006/`**

---

#### TensorBoardでチェックすべき主な項目
表示されたグラフの中で、今回の倒立振子の学習において特に重要な指標は以下の通りです。

* **`rollout/ep_rew_mean` (平均報酬):**
    * **最重要指標です。** 学習が進むにつれて右肩上がりに数値が増えていれば、AIは「より長く立つ」「より垂直を保つ」方法を学んでいる証拠です。
* **`rollout/ep_len_mean` (平均エピソード長):**
    * エピソードが終了（転倒）するまでのステップ数です。これが最大値（設定したタイムリミット）に張り付くようになれば、安定して立ち続けられていることを意味します。

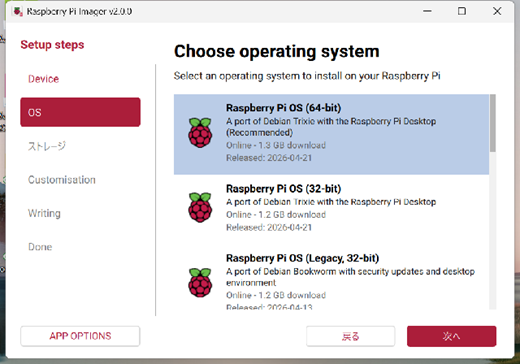
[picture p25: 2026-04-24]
pics_prog/pi4_2.png

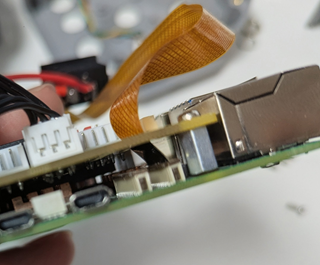
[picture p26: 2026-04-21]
pics_elec/flatCable.png

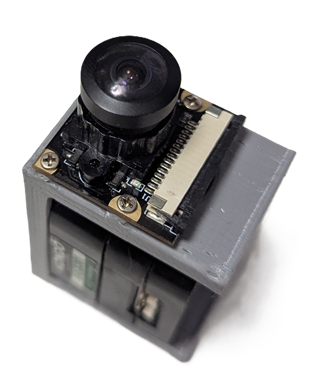
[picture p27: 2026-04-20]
pics_mech/panCamAsy.png

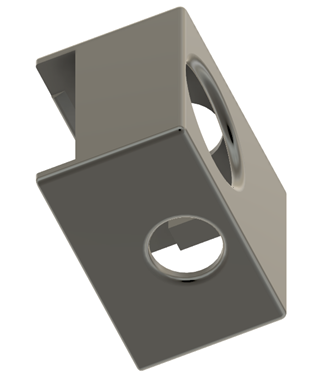
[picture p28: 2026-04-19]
pics_mech/camera_cover.png

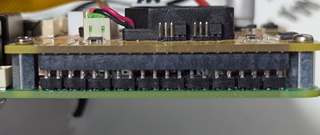
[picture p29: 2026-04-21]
pics_mech/distance2.png

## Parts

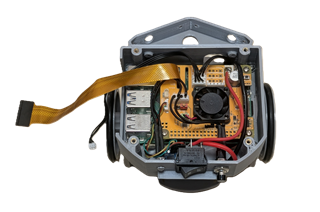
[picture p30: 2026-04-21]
pics_mech/allParts2.png

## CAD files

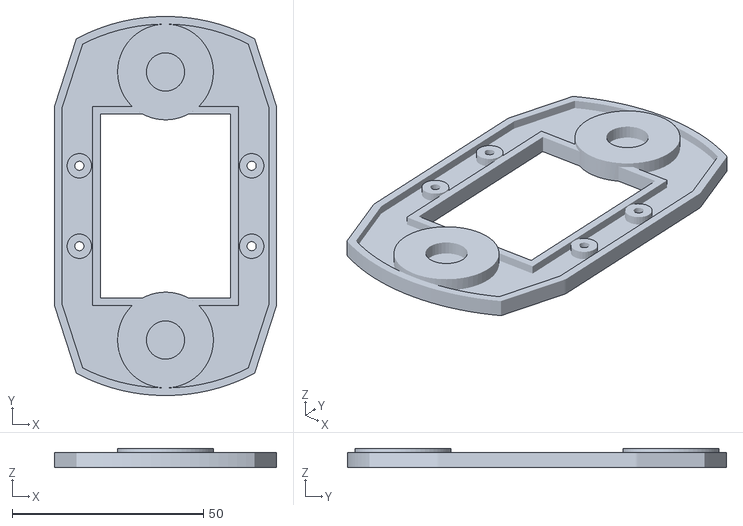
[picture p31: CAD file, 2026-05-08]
example/balance/assets/chasis.stl
58.0 x 99.0 x 5.00

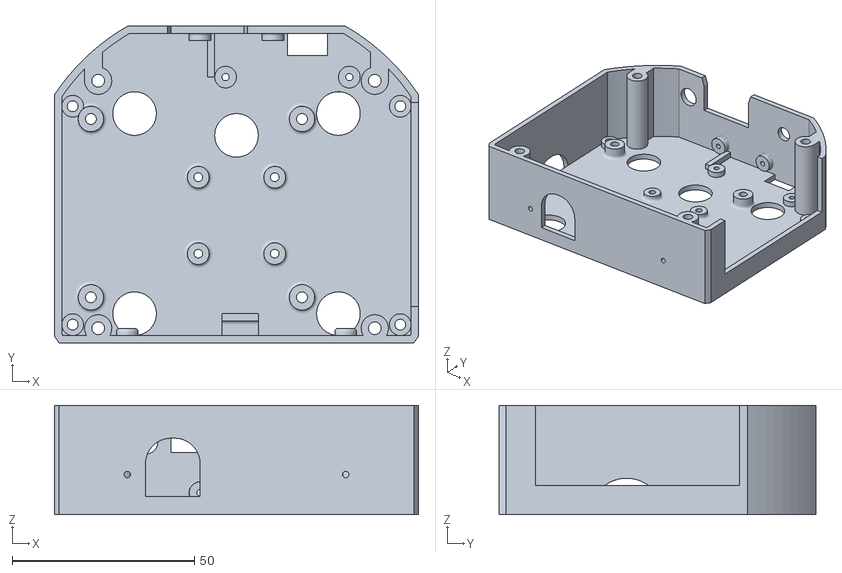
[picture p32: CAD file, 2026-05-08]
example/getup/assets/cpubox.stl
100.0 x 87.0 x 30.0

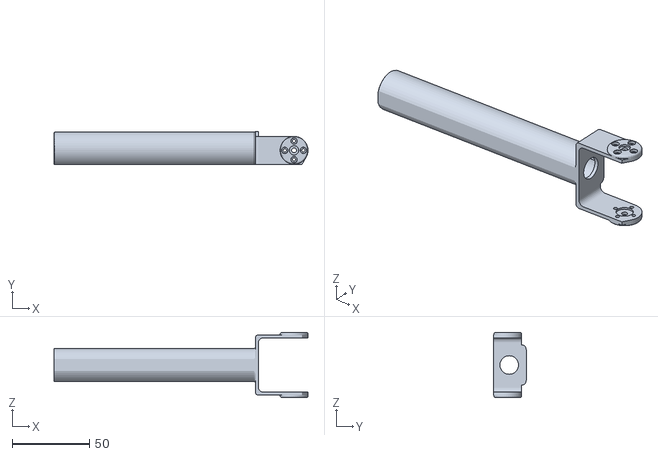
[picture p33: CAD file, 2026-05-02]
stl/arm_asy_long.stl
164.0 x 21.0 x 42.0

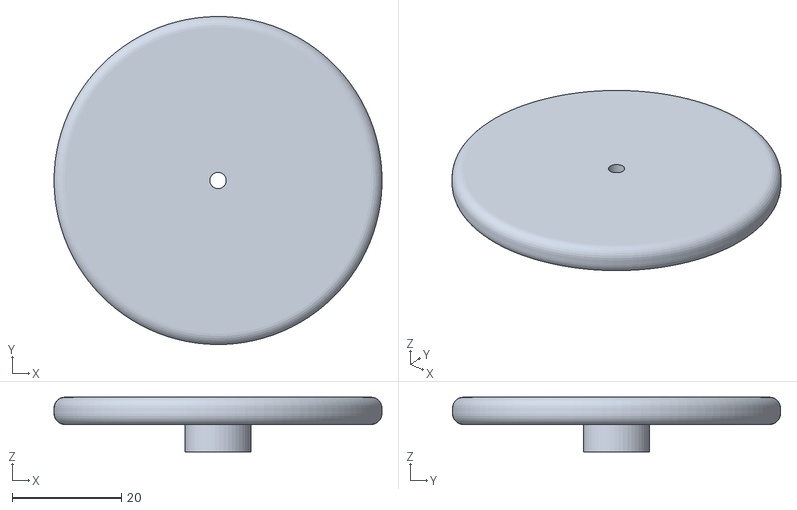
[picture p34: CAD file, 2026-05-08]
example/getup/assets/wheels.stl
60.0 x 60.0 x 10.0

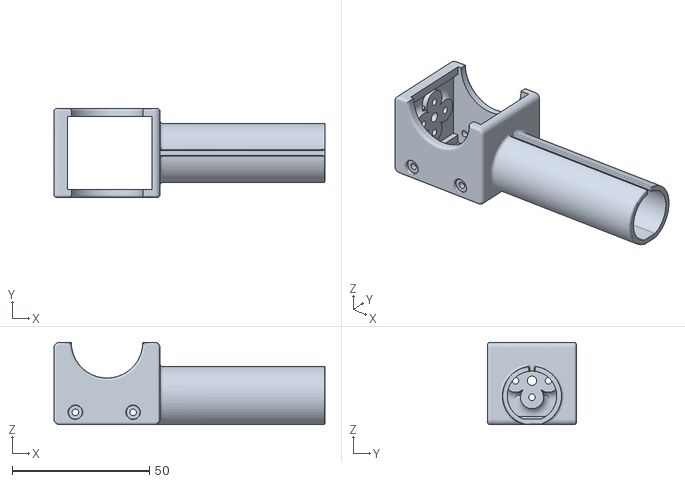
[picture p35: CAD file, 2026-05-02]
stl/Tilt_head_long.stl
98.6 x 32.4 x 30.0

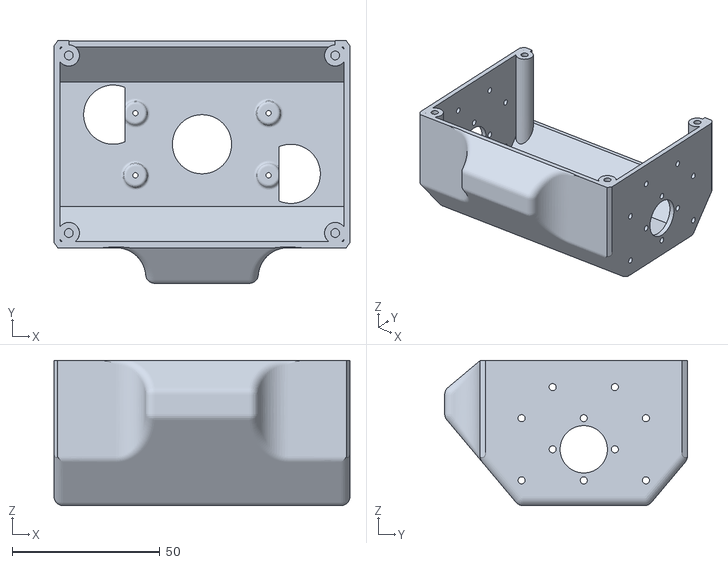
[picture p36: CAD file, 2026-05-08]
example/balance/assets/body.stl
100.0 x 82.0 x 49.0

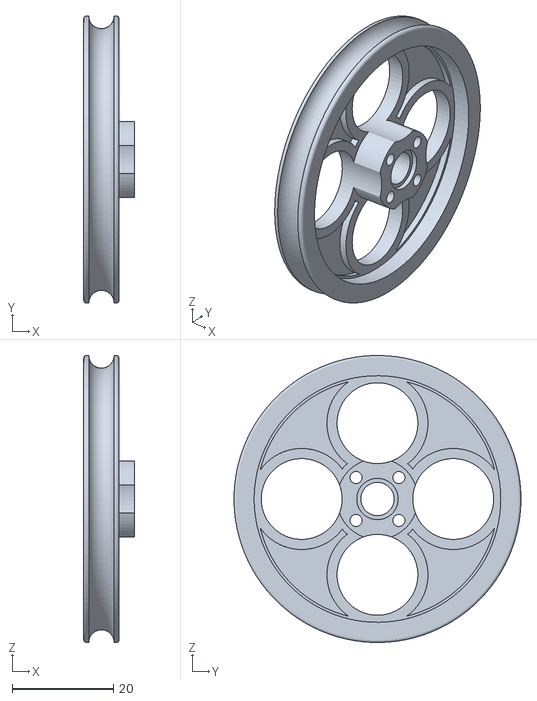
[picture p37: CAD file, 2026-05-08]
example/getup/assets/wheel.stl
10.0 x 56.8 x 56.8

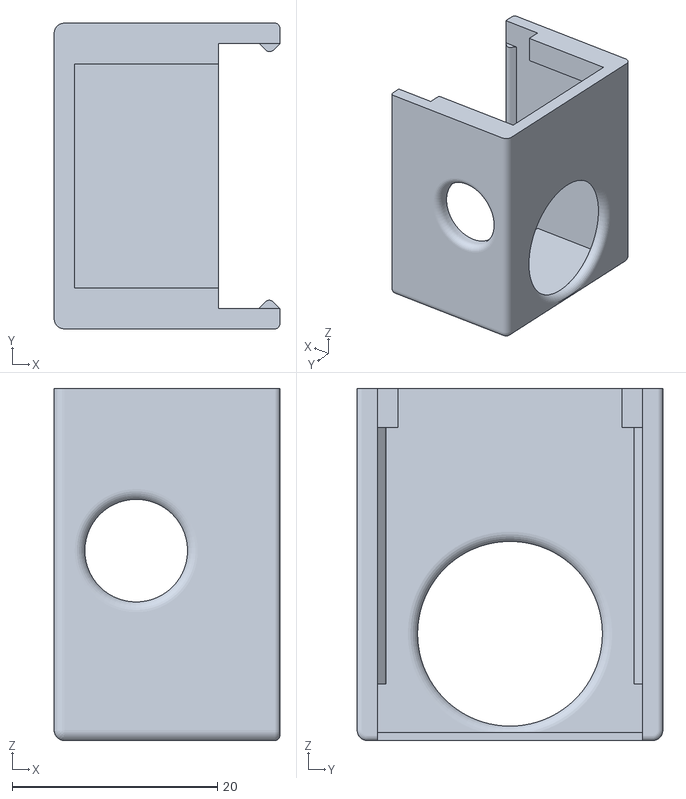
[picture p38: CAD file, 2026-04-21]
stl/camera_cover.stl
22.0 x 29.8 x 34.3

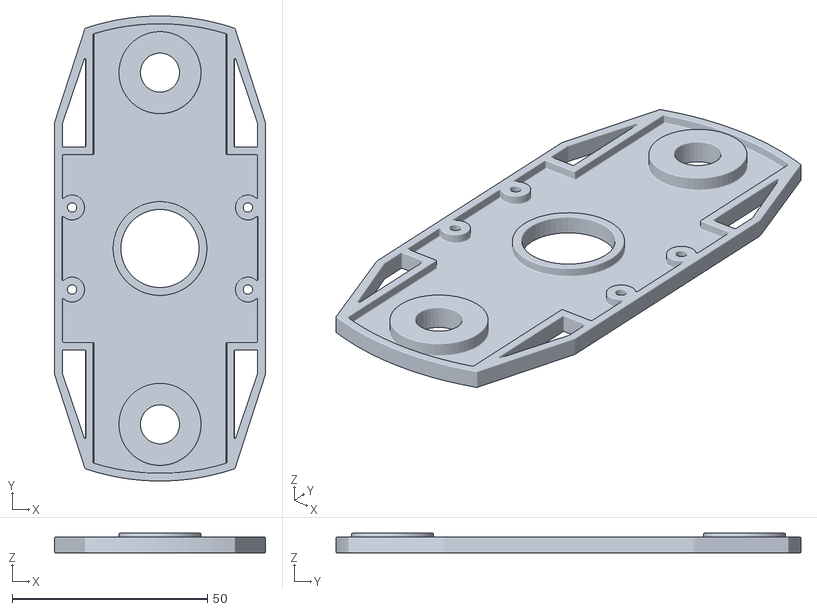
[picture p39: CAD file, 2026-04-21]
stl/Chassis_V_90.stl
54.0 x 119.0 x 5.00

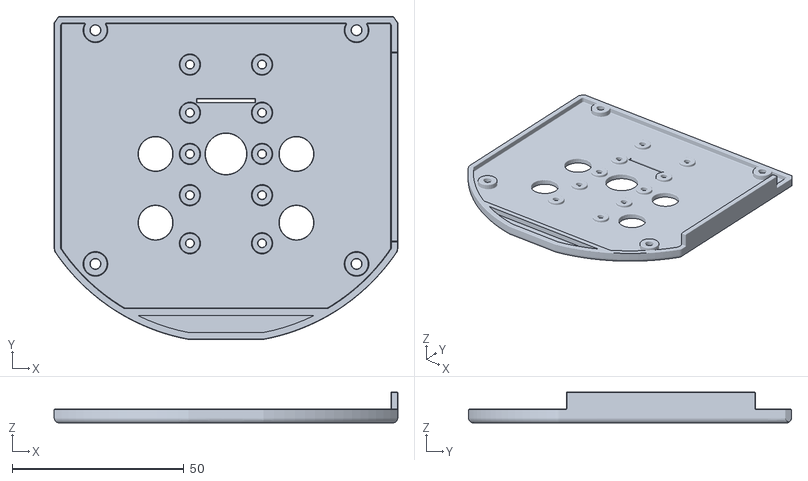
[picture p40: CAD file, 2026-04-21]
stl/CPU_cover.stl
100.0 x 94.0 x 9.00

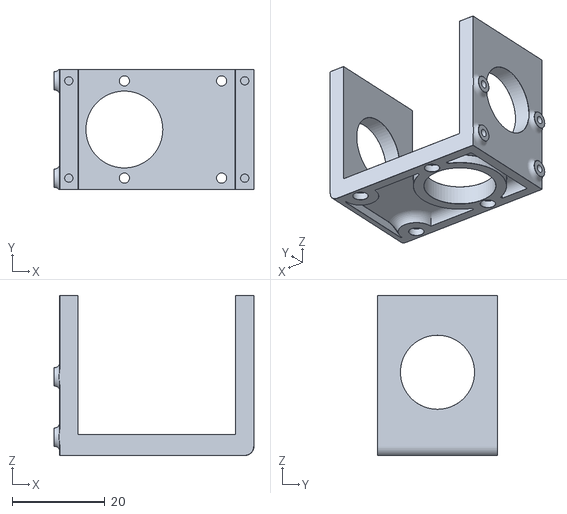
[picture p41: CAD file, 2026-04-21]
stl/Pan_stand.stl
43.2 x 26.0 x 34.6

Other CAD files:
stl/Body_V.stl
stl/Wheel_V.stl
stl/Arm v1.stl
stl/Battery_cover.stl
stl/CPU_case.stl
stl/Chassis_V_50.stl
stl/Chassis_V_70.stl
stl/Head v1.stl
stl/Psd1_bkt v6.stl
stl/psd2_bkt.stl

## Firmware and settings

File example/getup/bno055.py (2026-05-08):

import smbus
import time
import struct

class BNO055:
	BNO055_ADDRESS_A 				= 0x28
	BNO055_ADDRESS_B 				= 0x29
	BNO055_ID 		 			    = 0xA0

	# Power mode settings
	POWER_MODE_NORMAL   				= 0X00
	POWER_MODE_LOWPOWER 				= 0X01
	POWER_MODE_SUSPEND  				= 0X02

	# Operation mode settings
	OPERATION_MODE_CONFIG 				= 0X00
	OPERATION_MODE_ACCONLY 				= 0X01
	OPERATION_MODE_MAGONLY 				= 0X02
	OPERATION_MODE_GYRONLY 				= 0X03
	OPERATION_MODE_ACCMAG 				= 0X04
	OPERATION_MODE_ACCGYRO 				= 0X05
	OPERATION_MODE_MAGGYRO 				= 0X06
	OPERATION_MODE_AMG 				= 0X07
	OPERATION_MODE_IMUPLUS 				= 0X08
	OPERATION_MODE_COMPASS 				= 0X09
	OPERATION_MODE_M4G 				= 0X0A
	OPERATION_MODE_NDOF_FMC_OFF 			= 0X0B
	OPERATION_MODE_NDOF 				= 0X0C

	# Output vector type
	VECTOR_ACCELEROMETER 				= 0x08
	VECTOR_MAGNETOMETER  				= 0x0E
	VECTOR_GYROSCOPE     				= 0x14
	VECTOR_EULER         				= 0x1A
	VECTOR_LINEARACCEL   				= 0x28
	VECTOR_GRAVITY       				= 0x2E

	# REGISTER DEFINITION START
	BNO055_PAGE_ID_ADDR 				= 0X07

	BNO055_CHIP_ID_ADDR 				= 0x00
	BNO055_ACCEL_REV_ID_ADDR 			= 0x01
	BNO055_MAG_REV_ID_ADDR 				= 0x02
	BNO055_GYRO_REV_ID_ADDR 			= 0x03
	BNO055_SW_REV_ID_LSB_ADDR 			= 0x04
	BNO055_SW_REV_ID_MSB_ADDR 			= 0x05
	BNO055_BL_REV_ID_ADDR 				= 0X06

	# Accel data register 
	BNO055_ACCEL_DATA_X_LSB_ADDR 			= 0X08
	BNO055_ACCEL_DATA_X_MSB_ADDR 			= 0X09
	BNO055_ACCEL_DATA_Y_LSB_ADDR 			= 0X0A
	BNO055_ACCEL_DATA_Y_MSB_ADDR 			= 0X0B
	BNO055_ACCEL_DATA_Z_LSB_ADDR 			= 0X0C
	BNO055_ACCEL_DATA_Z_MSB_ADDR 			= 0X0D

	# Mag data register 
	BNO055_MAG_DATA_X_LSB_ADDR 			= 0X0E
	BNO055_MAG_DATA_X_MSB_ADDR 			= 0X0F
	BNO055_MAG_DATA_Y_LSB_ADDR 			= 0X10
	BNO055_MAG_DATA_Y_MSB_ADDR 			= 0X11
	BNO055_MAG_DATA_Z_LSB_ADDR 			= 0X12
	BNO055_MAG_DATA_Z_MSB_ADDR			= 0X13

	# Gyro data registers 
	BNO055_GYRO_DATA_X_LSB_ADDR 			= 0X14
	BNO055_GYRO_DATA_X_MSB_ADDR 			= 0X15
	BNO055_GYRO_DATA_Y_LSB_ADDR 			= 0X16
	BNO055_GYRO_DATA_Y_MSB_ADDR 			= 0X17
	BNO055_GYRO_DATA_Z_LSB_ADDR 			= 0X18
	BNO055_GYRO_DATA_Z_MSB_ADDR 			= 0X19
	
	# Euler data registers 
	BNO055_EULER_H_LSB_ADDR 			= 0X1A
	BNO055_EULER_H_MSB_ADDR 			= 0X1B
	BNO055_EULER_R_LSB_ADDR 			= 0X1C
	BNO055_EULER_R_MSB_ADDR 			= 0X1D
	BNO055_EULER_P_LSB_ADDR 			= 0X1E
	BNO055_EULER_P_MSB_ADDR 			= 0X1F

	# Quaternion data registers 
	BNO055_QUATERNION_DATA_W_LSB_ADDR 		= 0X20
	BNO055_QUATERNION_DATA_W_MSB_ADDR 		= 0X21
	BNO055_QUATERNION_DATA_X_LSB_ADDR 		= 0X22
	BNO055_QUATERNION_DATA_X_MSB_ADDR 		= 0X23
	BNO055_QUATERNION_DATA_Y_LSB_ADDR 		= 0X24
	BNO055_QUATERNION_DATA_Y_MSB_ADDR 		= 0X25
	BNO055_QUATERNION_DATA_Z_LSB_ADDR 		= 0X26
	BNO055_QUATERNION_DATA_Z_MSB_ADDR 		= 0X27

	# Linear acceleration data registers 
	BNO055_LINEAR_ACCEL_DATA_X_LSB_ADDR 		= 0X28
	BNO055_LINEAR_ACCEL_DATA_X_MSB_ADDR 		= 0X29
	BNO055_LINEAR_ACCEL_DATA_Y_LSB_ADDR	 	= 0X2A
	BNO055_LINEAR_ACCEL_DATA_Y_MSB_ADDR		= 0X2B
	BNO055_LINEAR_ACCEL_DATA_Z_LSB_ADDR		= 0X2C
	BNO055_LINEAR_ACCEL_DATA_Z_MSB_ADDR		= 0X2D

	# Gravity data registers 
	BNO055_GRAVITY_DATA_X_LSB_ADDR 			= 0X2E
	BNO055_GRAVITY_DATA_X_MSB_ADDR	 		= 0X2F
	BNO055_GRAVITY_DATA_Y_LSB_ADDR 			= 0X30
	BNO055_GRAVITY_DATA_Y_MSB_ADDR 			= 0X31
	BNO055_GRAVITY_DATA_Z_LSB_ADDR 			= 0X32
	BNO055_GRAVITY_DATA_Z_MSB_ADDR 			= 0X33

	# Temperature data register 
	BNO055_TEMP_ADDR 				= 0X34

	# Status registers 
	BNO055_CALIB_STAT_ADDR 				= 0X35
	BNO055_SELFTEST_RESULT_ADDR	 		= 0X36
	BNO055_INTR_STAT_ADDR 				= 0X37

	BNO055_SYS_CLK_STAT_ADDR 			= 0X38
	BNO055_SYS_STAT_ADDR 				= 0X39
	BNO055_SYS_ERR_ADDR 				= 0X3A

	# Unit selection register 
	BNO055_UNIT_SEL_ADDR 				= 0X3B
	BNO055_DATA_SELECT_ADDR 			= 0X3C

	# Mode registers 
	BNO055_OPR_MODE_ADDR 				= 0X3D
	BNO055_PWR_MODE_ADDR 				= 0X3E

	BNO055_SYS_TRIGGER_ADDR 			= 0X3F
	BNO055_TEMP_SOURCE_ADDR 			= 0X40

	# Axis remap registers 
	BNO055_AXIS_MAP_CONFIG_ADDR 		= 0X41
	BNO055_AXIS_MAP_SIGN_ADDR 			= 0X42

	# SIC registers 
	BNO055_SIC_MATRIX_0_LSB_ADDR 			= 0X43
	BNO055_SIC_MATRIX_0_MSB_ADDR 			= 0X44
	BNO055_SIC_MATRIX_1_LSB_ADDR 			= 0X45
	BNO055_SIC_MATRIX_1_MSB_ADDR 			= 0X46
	BNO055_SIC_MATRIX_2_LSB_ADDR 			= 0X47
	BNO055_SIC_MATRIX_2_MSB_ADDR 			= 0X48
	BNO055_SIC_MATRIX_3_LSB_ADDR 			= 0X49
	BNO055_SIC_MATRIX_3_MSB_ADDR 			= 0X4A
	BNO055_SIC_MATRIX_4_LSB_ADDR 			= 0X4B
	BNO055_SIC_MATRIX_4_MSB_ADDR 			= 0X4C
	BNO055_SIC_MATRIX_5_LSB_ADDR 			= 0X4D
	BNO055_SIC_MATRIX_5_MSB_ADDR 			= 0X4E
	BNO055_SIC_MATRIX_6_LSB_ADDR 			= 0X4F
	BNO055_SIC_MATRIX_6_MSB_ADDR 			= 0X50
	BNO055_SIC_MATRIX_7_LSB_ADDR 			= 0X51
	BNO055_SIC_MATRIX_7_MSB_ADDR 			= 0X52
	BNO055_SIC_MATRIX_8_LSB_ADDR 			= 0X53
	BNO055_SIC_MATRIX_8_MSB_ADDR 			= 0X54
	
	# Accelerometer Offset registers	 
	ACCEL_OFFSET_X_LSB_ADDR 			= 0X55
	ACCEL_OFFSET_X_MSB_ADDR 			= 0X56
	ACCEL_OFFSET_Y_LSB_ADDR 			= 0X57
	ACCEL_OFFSET_Y_MSB_ADDR 			= 0X58
	ACCEL_OFFSET_Z_LSB_ADDR 			= 0X59
	ACCEL_OFFSET_Z_MSB_ADDR 			= 0X5A

	# Magnetometer Offset registers 
	MAG_OFFSET_X_LSB_ADDR 				= 0X5B
	MAG_OFFSET_X_MSB_ADDR 				= 0X5C
	MAG_OFFSET_Y_LSB_ADDR 				= 0X5D
	MAG_OFFSET_Y_MSB_ADDR 				= 0X5E
	MAG_OFFSET_Z_LSB_ADDR 				= 0X5F
	MAG_OFFSET_Z_MSB_ADDR 				= 0X60

	# Gyroscope Offset registers
	GYRO_OFFSET_X_LSB_ADDR 				= 0X61
	GYRO_OFFSET_X_MSB_ADDR 				= 0X62
	GYRO_OFFSET_Y_LSB_ADDR 				= 0X63
	GYRO_OFFSET_Y_MSB_ADDR 				= 0X64
	GYRO_OFFSET_Z_LSB_ADDR 				= 0X65
	GYRO_OFFSET_Z_MSB_ADDR 				= 0X66

	# Radius registers 
	ACCEL_RADIUS_LSB_ADDR 				= 0X67
	ACCEL_RADIUS_MSB_ADDR 				= 0X68
	MAG_RADIUS_LSB_ADDR 				= 0X69
	MAG_RADIUS_MSB_ADDR 				= 0X6A

	# REGISTER DEFINITION END


	def __init__(self, sensorId=-1, address=0x28):
		self._sensorId = sensorId
		self._address = address
		self._mode = BNO055.OPERATION_MODE_NDOF


	def begin(self, mode=None):
		if mode is None: mode = BNO055.OPERATION_MODE_NDOF
		# Open I2C bus
		self._bus = smbus.SMBus(1)

		# Make sure we have the right device
		if self.readBytes(BNO055.BNO055_CHIP_ID_ADDR)[0] != BNO055.BNO055_ID:
			time.sleep(1)	# Wait for the device to boot up
			if self.readBytes(BNO055.BNO055_CHIP_ID_ADDR)[0] != BNO055.BNO055_ID:
				return False

		# Switch to config mode
		self.setMode(BNO055.OPERATION_MODE_CONFIG)

		# Trigger a reset and wait for the device to boot up again
		self.writeBytes(BNO055.BNO055_SYS_TRIGGER_ADDR, [0x20])
		time.sleep(1)
		while self.readBytes(BNO055.BNO055_CHIP_ID_ADDR)[0] != BNO055.BNO055_ID:
			time.sleep(0.01)
		time.sleep(0.05)

		# Set to normal power mode
		self.writeBytes(BNO055.BNO055_PWR_MODE_ADDR, [BNO055.POWER_MODE_NORMAL])
		time.sleep(0.01)

		self.writeBytes(BNO055.BNO055_PAGE_ID_ADDR, [0])
		self.writeBytes(BNO055.BNO055_SYS_TRIGGER_ADDR, [0])
		time.sleep(0.01)

		# Set the requested mode
		self.setMode(mode)
		time.sleep(0.02)

		return True

	def setMode(self, mode):
		self._mode = mode
		self.writeBytes(BNO055.BNO055_OPR_MODE_ADDR, [self._mode])
		time.sleep(0.03)

	def setExternalCrystalUse(self, useExternalCrystal = True):
		prevMode = self._mode
		self.setMode(BNO055.OPERATION_MODE_CONFIG)
		time.sleep(0.025)
		self.writeBytes(BNO055.BNO055_PAGE_ID_ADDR, [0])
		self.writeBytes(BNO055.BNO055_SYS_TRIGGER_ADDR, [0x80] if useExternalCrystal else [0])
		time.sleep(0.01)
		self.setMode(prevMode)
		time.sleep(0.02)

	def getSystemStatus(self):
		self.writeBytes(BNO055.BNO055_PAGE_ID_ADDR, [0])
		(sys_stat, sys_err) = self.readBytes(BNO055.BNO055_SYS_STAT_ADDR, 2)
		self_test = self.readBytes(BNO055.BNO055_SELFTEST_RESULT_ADDR)[0]
		return (sys_stat, self_test, sys_err)

	def getRevInfo(self):
		(accel_rev, mag_rev, gyro_rev) = self.readBytes(BNO055.BNO055_ACCEL_REV_ID_ADDR, 3)
		sw_rev = self.readBytes(BNO055.BNO055_SW_REV_ID_LSB_ADDR, 2)
		sw_rev = sw_rev[0] | sw_rev[1] << 8
		bl_rev = self.readBytes(BNO055.BNO055_BL_REV_ID_ADDR)[0]
		return (accel_rev, mag_rev, gyro_rev, sw_rev, bl_rev)

	def getCalibration(self):
		calData = self.readBytes(BNO055.BNO055_CALIB_STAT_ADDR)[0]
		return (calData >> 6 & 0x03, calData >> 4 & 0x03, calData >> 2 & 0x03, calData & 0x03)

	def getTemp(self):
		return self.readBytes(BNO055.BNO055_TEMP_ADDR)[0]

	def getVector(self, vectorType):
		buf = self.readBytes(vectorType, 6)
		xyz = struct.unpack('hhh', struct.pack('BBBBBB', buf[0], buf[1], buf[2], buf[3], buf[4], buf[5]))
		if vectorType == BNO055.VECTOR_MAGNETOMETER:	scalingFactor = 16.0
		elif vectorType == BNO055.VECTOR_GYROSCOPE:	scalingFactor = 900.0
		elif vectorType == BNO055.VECTOR_EULER: 		scalingFactor = 16.0
		elif vectorType == BNO055.VECTOR_GRAVITY:	scalingFactor = 100.0
		else:											scalingFactor = 1.0
		return tuple([i/scalingFactor for i in xyz])

	def getQuat(self):
		buf = self.readBytes(BNO055.BNO055_QUATERNION_DATA_W_LSB_ADDR, 8)
		wxyz = struct.unpack('hhhh', struct.pack('BBBBBBBB', buf[0], buf[1], buf[2], buf[3], buf[4], buf[5], buf[6], buf[7]))
		return tuple([i * (1.0 / (1 << 14)) for i in wxyz])

	def readBytes(self, register, numBytes=1):
		return self._bus.read_i2c_block_data(self._address, register, numBytes)

	def writeBytes(self, register, byteVals):
		return self._bus.write_i2c_block_data(self._address, register, byteVals)


if __name__ == '__main__':
	bno = BNO055()
	if bno.begin() is not True:
		print("Error initializing device")
		exit()
	time.sleep(1)
	bno.setExternalCrystalUse(True)
	while True:
		#print(bno.getVector(BNO055.VECTOR_EULER))
		print(bno.getVector(BNO055.VECTOR_GYROSCOPE))
		#print(bno.getQuat())
		#print(bno.getVector(BNO055.VECTOR_GRAVITY))
		time.sleep(0.1)

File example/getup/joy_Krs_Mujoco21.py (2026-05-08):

#!/usr/bin/env python
# Beginners KRS-servo Joy MuJoCo program
# 2026.5.1
# by T.Nishimura of AiRRC
#--------------------------------
import mujoco
import mujoco.viewer
import numpy as np
import serial
import math
import time
from stable_baselines3 import PPO
from krs_driver_rp5 import * 
from bno055 import *
import pygame
#---------------
#set servo para
id_r=1
id_l=2
id_pan=3
id_tilt=4
#
ct=7500
ct_pan=6078
ct_tilt=7500
max_tilt=9600
min_tilt=5870
last_time = time.time()
tilt_p_pos=0
pan_p_pos=0
#
krs=KRSdriver()
#----------------
bno = BNO055()
if bno.begin() is not True:
	print("Error initializing BNO055")
	exit()
time.sleep(1)
bno.setExternalCrystalUse(True)
# ---------------
def free_all():
    for i in range(4):
        krs.read_position_set_free(i+1)
#----------------------------------------
def main():
    global last_time,tilt_p_pos,pan_p_pos
    free_all()
    # モデルのロード
    model_path = "robot4_getup1.zip"
    try:
        model = PPO.load(model_path)
        print(f"Loaded: {model_path}")
    except:
        print("モデルファイルが見つかりません。")
        return    
  # Pygameの初期化（コントローラー用）
    pygame.init()
    pygame.joystick.init()
    free_all()
    while pygame.joystick.get_count() == 0:
        pygame.event.pump() # イベントキューを更新
        time.sleep(0.1)     # CPU負荷を抑えるための待機
    joystick = pygame.joystick.Joystick(0)
    joystick.init()
    print(f"Using: {joystick.get_name()}")

   # MuJoCoの準備
    model_mj = mujoco.MjModel.from_xml_path('2wheel_im_krs.xml')
    data_mj = mujoco.MjData(model_mj)
    
   # IDのキャッシュ (Observation作成用)
    base_id = mujoco.mj_name2id(model_mj, mujoco.mjtObj.mjOBJ_BODY, "base_link")

    def get_obs():
        """学習時と完全に同じObservation(21次元)を作成"""
        qpos = data_mj.qpos.flat.copy()
        qvel = data_mj.qvel.flat.copy()
        return np.concatenate([qpos, qvel]).astype(np.float32)
    def side_d():
        # 状態: qpos(11) + qvel(10) = 21
        qpos = data_mj.qpos.flat.copy()
        qvel = data_mj.qvel.flat.copy()
        data_mj.qpos[3:7] =[ -0.707, 0 ,0.707, 0]
        return np.concatenate([qpos, qvel]).astype(np.float32)
  #-----------------------------------
    def get_real_obs():
        global last_time,tilt_p_pos,pan_p_pos
        """学習時と完全に同じObservation(21次元)を作成"""
      # 状態: qpos(11) + qvel(10) = 21
        qpos = data_mj.qpos.flat.copy()
        qvel = data_mj.qvel.flat.copy()
      # 直立時に 1.0, 転倒時に 0.0重力ベクトルのZ成分を使用
      #  gravity = bno.getVector(BNO055.VECTOR_GRAVITY) # g(x,y,z)
      #  upright = gravity[2] / 9.8 
      #  side_tilt =  gravity[1] / 9.8
      #  front_tilt =  gravity[0] / 9.8
      #print(upright,side_tilt,front_tilt)
      # -----------------
      # positionq  pos(11)
        pan_pos=(krs.read_position(3)-ct_pan-1000)/3500
        if pan_pos>1.0:
            pan_pos=1.0
        if pan_pos<-1.0:
            pan_pos=-1.0
        #print(pan_pos)
        tilt_pos=(krs.read_position(4)-min_tilt)*2.0/(max_tilt-min_tilt)-1.0 
        if tilt_pos>1.0:
            tilt_pos=1.0
        if tilt_pos<-1.0:
            tilt_pos=-1.0
        #print(tilt_pos)
      # ------------
      # velocity
        now = time.time()
        dt = now-last_time
        tilt_vel=(tilt_pos-tilt_p_pos)/dt
        pan_vel=(pan_pos-pan_p_pos)/dt
        tilt_p_pos=tilt_pos
        pan_p_pos=pan_pos
        if dt <= 0:
            dt=0.1
        last_time = now
    ## 状態: qpos(11) + qvel(10) + upright(1) + side_tilt(1) = 23
     #
     ## qpos には、具体的に以下のような順番で数字が並んでいます：
     # インデックス意味
      # 0, 1, 2 本体の位置 (x, y, z)
        qpos[0]=0
        qpos[1]=0
        qpos[2]=0
      # 3, 4, 5, 6 本体の向き（クォータニオン）
        quat=bno.getQuat()
        qpos[3]=quat[0]
        qpos[4]=quat[1]
        qpos[5]=quat[2]
        qpos[6]=quat[3]
      # 7 右車輪の回転角
        qpos[7]=0
      # 8 左車輪の回転角
        qpos[8]=0
      # 9 アームのRoll角
        qpos[9]=pan_pos
      #10 アームのPitch角
        qpos[10]=-tilt_pos
    # qvel (対応する qpos よりも1つ要素が少なくなります)
          #（向きがクォータニオンではなく3軸の回転速度になるため）
      # 0, 1, 2 本体の移動速度 (vx, vy, vz)m/s
        qvel[0]=0
        qvel[1]=0
        qvel[2]=0
      # 3, 4, 5 本体の回転速度 (ロール, ピッチ, ヨー)rad/s
        qvel[3]=0
        qvel[4]=0
        qvel[5]=0    
      # 6 右車輪の回転速度rad/s
        qvel[6]=0   
      # 7 左車輪の回転速度rad/s
        qvel[7]=0   
      # 8 アームのRoll回転速度rad/s
        qvel[8]=pan_vel  
      # 9 アームのPitch回転速度rad/s
        qvel[9]=tilt_vel
        #return np.concatenate([qpos, qvel, [upright], [side_tilt]]).astype(np.float32)
        return np.concatenate([qpos, qvel]).astype(np.float32)
    # 鑑賞ループ
    with mujoco.viewer.launch_passive(model_mj, data_mj) as viewer:
        while viewer.is_running():
            step_start = time.time()
          # Joy stick
            pygame.event.pump()
            fr=joystick.get_axis(1)
            rl=joystick.get_axis(0)
            pan=joystick.get_axis(2)
            tilt=joystick.get_axis(3)
            bu=joystick.get_button(0) # A
            bu2=joystick.get_button(1)# B
            bu3=joystick.get_button(3)# X
            bu4=joystick.get_button(4)# Y
            bu6=joystick.get_button(6)# L1
            bu7=joystick.get_button(7)# R1
            bu8=joystick.get_button(8)# L2
            bu9=joystick.get_button(9)# R2
            bu10=joystick.get_button(10)# -
            #print(joystick.get_button(10))
            if bu!=0: #A
            # Mujoco obs
                obs = get_obs()
                action, _ = model.predict(obs, deterministic=True)
                data_mj.ctrl[:] = [action[0]*7.8,action[1]*7.8,action[2]*3.14,action[3]*3.14]
            elif bu2!=0:#B
            # get obserbation data
                obs = get_real_obs()
                action, _ = model.predict(obs, deterministic=True)
              # 実機仕様のスケーリング適用
                krs.set_position_ret(1,int(350*action[0]+ct))
                krs.set_position_ret(2,int(-350*action[1]+ct))
                krs.set_position_ret(3,int(-3500*action[2]*1.57+ct_pan))
                krs.set_position_ret(4,int(-3500*action[3]*1.57+ct_tilt))
            elif bu3!=0:#Y
              # MuJoCoに適用
                obs = get_obs()
              # get quatanion
                quat=bno.getQuat()
              # set data
                data_mj.qpos[3:7] =quat
                data_mj.ctrl[:] = [action[0]*7.8,action[1]*7.8,action[2]*3.14,action[3]*3.14]
            elif bu8!=0: #L2
                obs = get_real_obs()
                print(obs)
            # set action data from joy stick
                action=[-fr-rl,-fr+rl,-pan,tilt]
                #print(fr,rl,pan,tilt)
                data_mj.ctrl[:] = [action[0]*7.8,action[1]*7.8,action[2]*3.14,action[3]*3.14]
              # 実機仕様のスケーリング適用
                krs.set_position_ret(1,int(350*action[0]+ct))
                krs.set_position_ret(2,int(-350*action[1]+ct))
                krs.set_position_ret(3,int(-3500*action[2]*1.57+ct_pan))
                krs.set_position_ret(4,int(-3500*action[3]*1.57+ct_tilt))
            elif bu6!=0: #L1
                free_all()
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

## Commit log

2026-02-26 Enhance Mechanical Design documentation with new sections
    Added detailed sections on CPU case, wheel, chassis, and caster for improved design documentation.
2026-03-16 Update Mechanical Design with new images
    Added new images for PSD brackets and arm bracket, and removed some redundant images.
2026-03-16 Update Electronic_Circuit.md with product links
    Added links for HeatSink and HAT for Raspi5.
2026-03-20 Document BNO055 sensor setup and inference process
    Added detailed instructions for setting up and using the BNO055 sensor with Raspberry Pi for real-world inference in simulations.
2026-03-20 Remove extensive BNO055 setup and deployment instructions
    Removed detailed instructions for hardware setup, software preparation, inference script, and tips for successful deployment of the BNO055 sensor in a real-world application.
2026-04-29 Update Simulation.md with new Mujoco and PID sections
    Added sections for Beginners Mujoco model and PID control for inverted pendulum.
2026-05-08 Remove migration instructions for BNO055 sensor
    Removed section on migrating simulation data for BNO055 sensor setup.
2026-08-01 Enhance Electronic Circuit documentation with cost-saving tips
    Added a low-cost version section with cost-saving tips and component links. Included assembly tips and wiring diagrams for clarity.
2026-08-01 Update Raspberry Pi 5 setup description
    Added details about the components used with the Raspberry Pi 5.
2026-08-01 Revise purchase links in Electronic_Circuit.md
    Updated purchase links for Raspberry Pi models and a DC-DC converter.
